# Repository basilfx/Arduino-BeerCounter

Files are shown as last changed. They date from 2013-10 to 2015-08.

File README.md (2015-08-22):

# BeerCounter
A beer cork counting system, built around an Arduino, with the love of beer.

## Contents
* Eagle schematic and PCB
* Arduino firmware

## Eagle

### Bill of materials
| Part | Value | Device | Package |
|---|---|---|---|
| C1 | 22pF | C-EU025-024X044 | C025-024X044 |
| C2 | 22pF | C-EU025-024X044 | C025-024X044 |
| C3 | 100nF | C-EU025-024X044 | C025-024X044 |
| C4 | | CPOL-EUTT2D5 | TT2D5 |
| C5 | 100nF | C-EU025-024X044 | C025-024X044 |
| IC1 | TL072P | TL072P | DIL08 |
| IC2 | MEGA8-P | MEGA8-P | DIL28-3 |
| ISP | AVR_SPI_PROG  | AVR_SPI_PROG | AVR_ICSP |
| J1 | POWER_JACKSLT | POWER_JACKSLT | POWER_JACK_SLOT |
| LDR1 | | M02LOCK | 1X02_LOCK |
| LDR2 | | M02LOCK | 1X02_LOCK |
| Q1 | 16MHz | XTAL/S | QS |
| R1 | 4k7 | R-EU_0204/7 | 0204/7 |
| R2 | 1M | R-EU_0204/7 | 0204/7 |
| R3 | 1M | R-EU_0204/7 | 0204/7 |
| R4 | 4k7 | TRIM_EU-LI10 | LI10 |
| R5 | 4k7 | TRIM_EU-LI10 | LI10 |
| R6 | 68k | R-EU_0204/7 | 0204/7 |
| R7 | 68k | R-EU_0204/7 | 0204/7 |
| R8 | 220 | R-EU_0204/7 | 0204/7 |
| R9 | 220 | R-EU_0204/7 | 0204/7 |
| R10 | 4k7 | R-EU_0204/7 | 0204/7 |
| S1 | | TAC_SWITCHPTH | TACTILE-PTH |
| S2 | | TAC_SWITCHPTH | TACTILE-PTH |

### Board render
Render of the controller board. It measures 2.05x2.30 inch

board_controller

Render of the display board. It measures 3.70x1.60 inch.

board_display

## Arduino
The source can be found under `firmware`. It's build with Arduino 1.6.5, but newer versions should work too.

You need the following libraries:
* [CommandLine](https://github.com/basilfx/Arduino-CommandLine)
* [Timer1](http://playground.arduino.cc/Code/Timer1)

### Firmware
To be done.

### Hardware configuration
For best performance, the light gate should be fitted in a tube, where environment light has little effect.

To calibrate the device, check the [calibration](https://github.com/basilfx/Arduino-BeerCounter/blob/master/docs/Calibration.md) guide.

### Firmware configuration
Once you have the device ready, connect it to the computer via a serial adapter. Hold the setup button, and power cycle the device. The settings for terminal are 115200 baud, 8 bits, no parity and 1 start/stop bit. The terminal has the following commands:

* reset &mdash; Reset the device
* count <value> &mdash; Get/set the initial count
* zeroes <1|0> &mdash; Enable/disable leading zeroes
* restarts &mdash; Get the number of power cycles

## License
See the `LICENSE` file (MIT license).

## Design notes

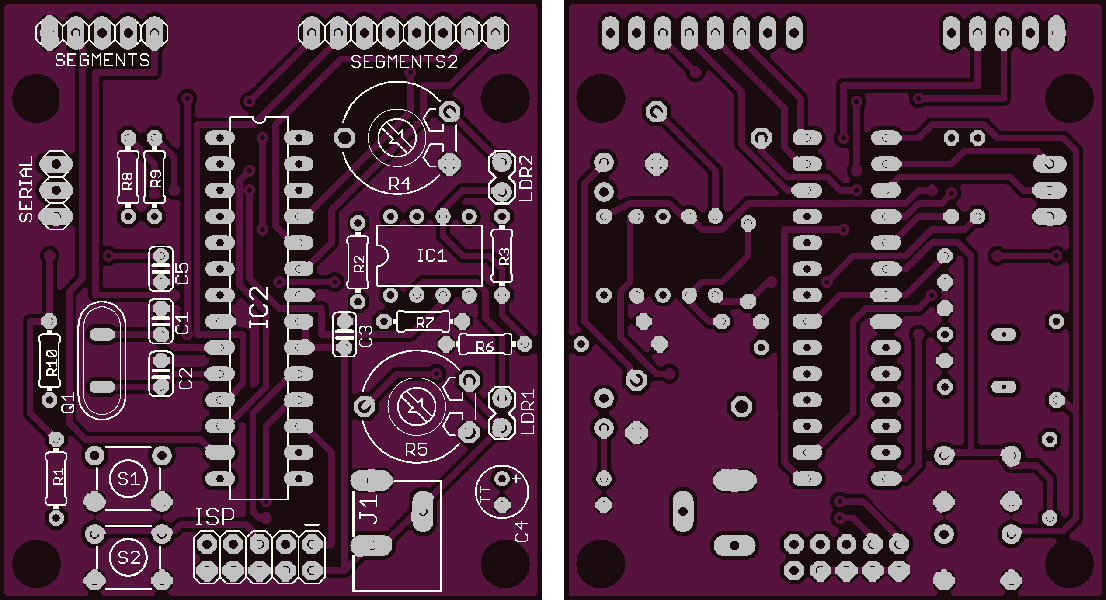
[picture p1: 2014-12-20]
docs/board_controller.png

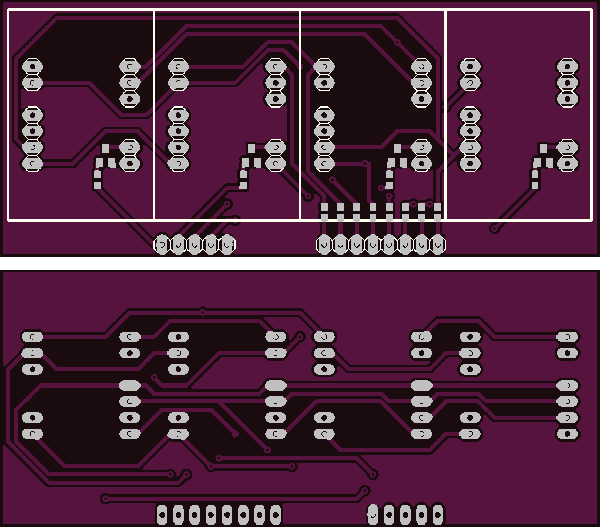
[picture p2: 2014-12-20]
docs/board_display.png

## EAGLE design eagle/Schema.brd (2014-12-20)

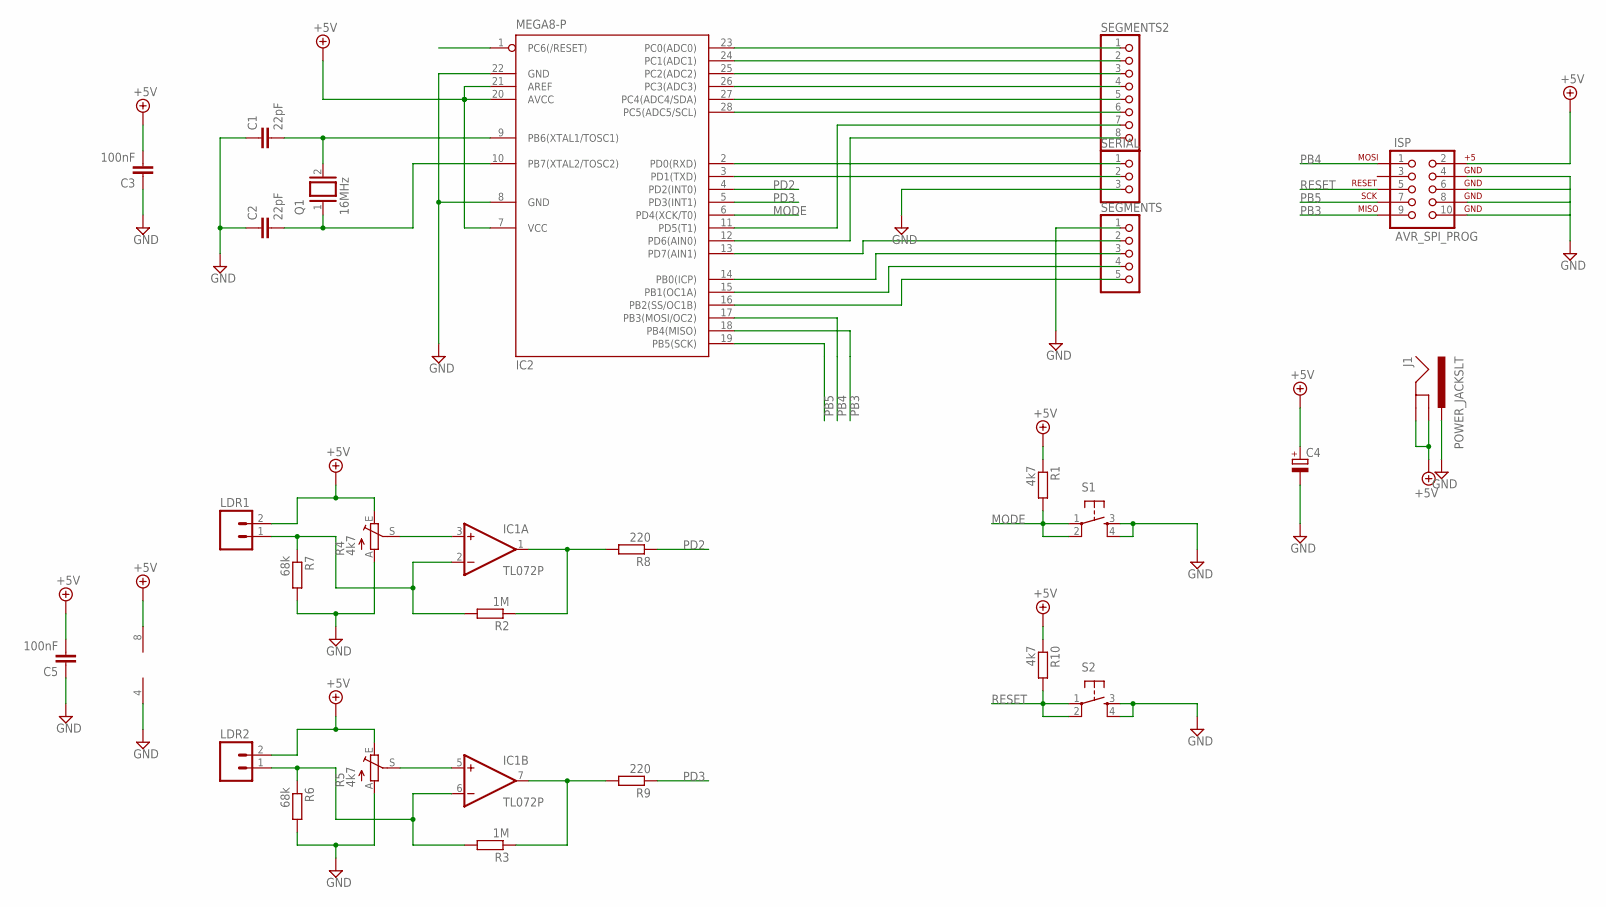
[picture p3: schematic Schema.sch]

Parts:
C1, C2: 22pF; C025-024X044
C3, C5: 100nF; C025-024X044
C4: CPOL-EUTT2D5; TT2D5
IC1: TL072P; DIL08
IC2: MEGA8-P; DIL28-3
ISP: AVR_SPI_PROG; AVR_ICSP
J1: POWER_JACKSLT; POWER_JACK_SLOT
LDR1, LDR2: M02LOCK; 1X02_LOCK
Q1: 16MHz; QS
R1, R10: 4k7; 0204/7
R2, R3: 1M; 0204/7
R4, R5: 4k7; LI10
R6, R7: 68k; 0204/7
R8, R9: 220; 0204/7
S1, S2: TAC_SWITCHPTH; TACTILE-PTH
SEGMENTS: PINHD-1X5; 1X05
SEGMENTS2: PINHD-1X8; 1X08
SERIAL: PINHD-1X3; 1X03

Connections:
+5V: C3.2, C4.+, C5.2, IC1.8 (V+), IC2.7 (VCC), IC2.20 (AVCC), IC2.21 (AREF), ISP.2, J1.GND@1 (GNDBREAK), J1.GND@2 (GND), LDR1.2, LDR2.2, R1.1, R4.E, R5.E, R10.1
GND: C1.1, C2.1, C3.1, C4.-, C5.1, IC1.4 (V-), IC2.8 (GND), IC2.22 (GND), ISP.4, ISP.6, ISP.8, ISP.10, J1.PWR, R4.A, R5.A, R6.2, R7.2, S1.3, S1.4, S2.3, S2.4, SEGMENTS.1, SERIAL.3
MODE: IC2.6 (PD4(XCK/T0)), R1.2, S1.1, S1.2
unnamed: C1.2, IC2.9 (PB6(XTAL1/TOSC1)), Q1.2
unnamed: C2.2, IC2.10 (PB7(XTAL2/TOSC2)), Q1.1
unnamed: IC1.1 (OUT), R2.1, R8.2
unnamed: IC2.3 (PD1(TXD)), SERIAL.2
unnamed: IC2.2 (PD0(RXD)), SERIAL.1
unnamed: IC1.7 (OUT), R3.1, R9.2
unnamed: IC1.3 (+IN), R4.S
unnamed: IC1.5 (+IN), R5.S
unnamed: IC1.6 (-IN), LDR2.1, R3.2, R6.1
unnamed: IC1.2 (-IN), LDR1.1, R2.2, R7.1
unnamed: IC2.16 (PB2(SS/OC1B)), SEGMENTS.5
unnamed: IC2.15 (PB1(OC1A)), SEGMENTS.4
unnamed: IC2.14 (PB0(ICP)), SEGMENTS.3
unnamed: IC2.24 (PC1(ADC1)), SEGMENTS2.2
unnamed: IC2.25 (PC2(ADC2)), SEGMENTS2.3
unnamed: IC2.26 (PC3(ADC3)), SEGMENTS2.4
unnamed: IC2.27 (PC4(ADC4/SDA)), SEGMENTS2.5
unnamed: IC2.28 (PC5(ADC5/SCL)), SEGMENTS2.6
unnamed: IC2.12 (PD6(AIN0)), SEGMENTS2.8
unnamed: IC2.11 (PD5(T1)), SEGMENTS2.7
unnamed: IC2.13 (PD7(AIN1)), SEGMENTS.2
PB3: IC2.18 (PB4(MISO)), ISP.9
PB4: IC2.17 (PB3(MOSI/OC2)), ISP.1
PB5: IC2.19 (PB5(SCK)), ISP.7
PD2: IC2.4 (PD2(INT0)), R8.1
PD3: IC2.5 (PD3(INT1)), R9.1
RESET: IC2.1 (PC6(/RESET)), ISP.5, R10.2, S2.1, S2.2
SEGMENTS: IC2.23 (PC0(ADC0)), SEGMENTS2.1

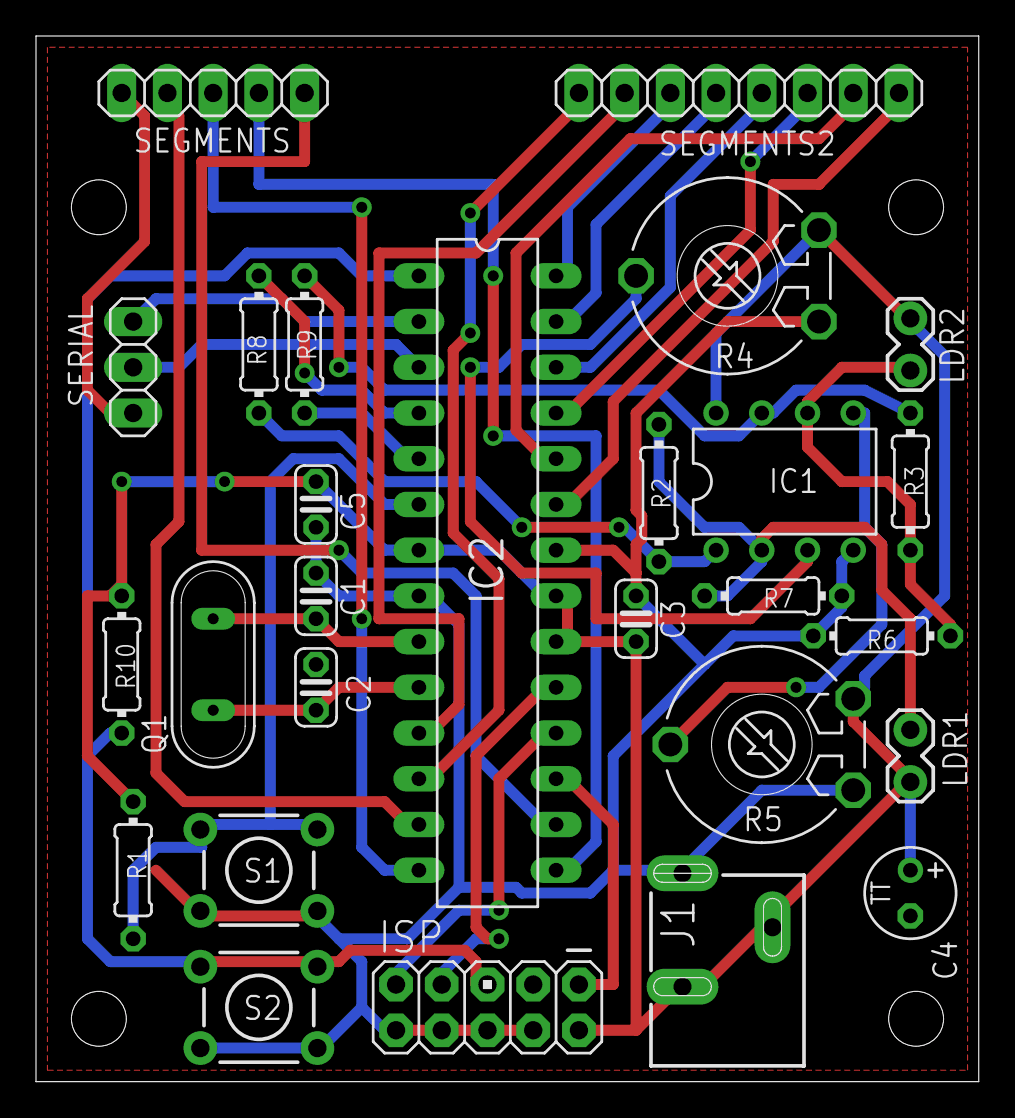
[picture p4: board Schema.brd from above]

Board: 2 copper layers, 52.4 x 58.1 mm, 31 parts (0 on the bottom side), 31 nets.

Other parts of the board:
U$2, U$3, U$4, U$5: STAND-OFF-TIGHT

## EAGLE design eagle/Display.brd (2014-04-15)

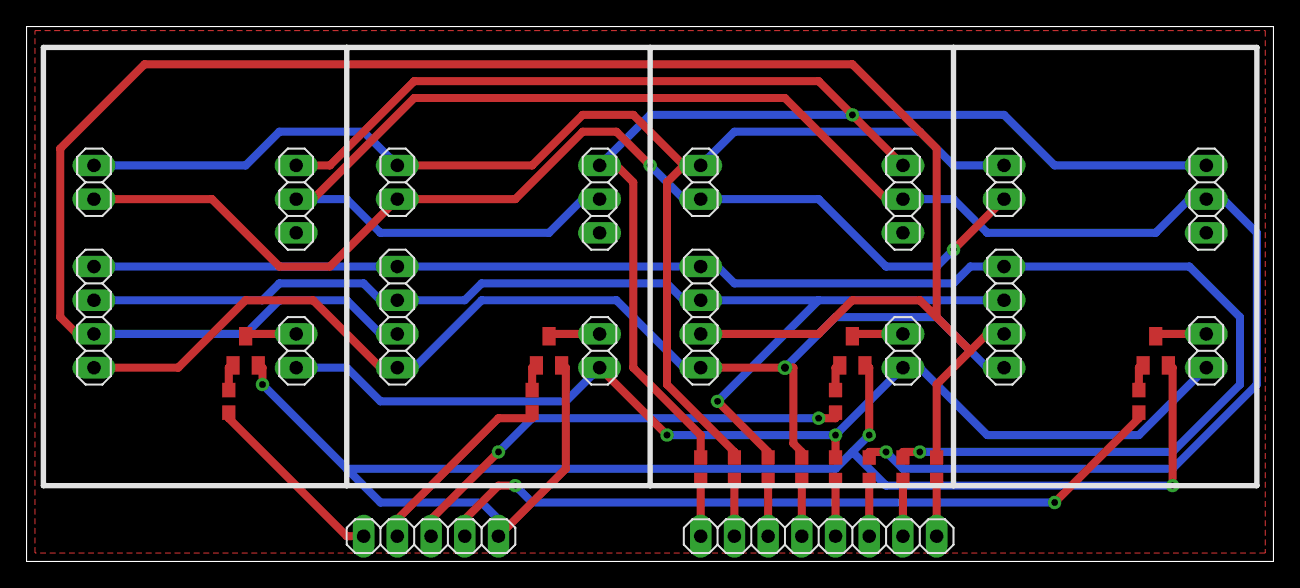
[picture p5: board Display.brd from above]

Board: 2 copper layers, 94.0 x 40.3 mm, 34 parts (0 on the bottom side), 30 nets.

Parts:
E$1, E$3, E$5, E$7, E$9, E$11, E$13, E$15: 1X02
E$2, E$6, E$10, E$14: 1X03
E$4, E$8, E$12, E$16: 1X04
E$17: 1X08
E$18, E$19, E$20, E$21, E$22, E$23, E$24, E$25, E$26, E$32, E$33, E$34: 0603
E$27, E$28, E$29, E$30: SOT23
E$31: 1X05

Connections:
GND: E$27.2, E$28.2, E$29.2, E$30.2, E$31.5
S$1: E$2.3, E$6.3, E$10.3, E$14.3, E$19.2
S$2: E$3.2, E$7.2, E$11.2, E$15.2, E$20.2
S$3: E$3.1, E$7.1, E$11.1, E$15.1
S$4: E$2.2, E$6.2, E$10.2, E$14.2, E$24.2
S$5: E$4.4, E$8.4, E$12.4, E$16.4, E$25.2
S$6: E$4.3, E$8.3, E$12.3, E$16.3, E$21.2
S$7: E$1.1, E$5.1, E$9.1, E$13.1, E$23.2
S$8: E$4.1, E$8.1, E$12.1, E$16.1, E$22.2
S$9: E$4.2, E$8.2, E$12.2, E$16.2, E$26.2
S$10: E$17.1, E$19.1
S$11: E$17.2, E$20.1
S$12: E$17.3, E$21.1
S$13: E$17.4, E$22.1
S$14: E$17.5, E$23.1
S$15: E$17.6, E$24.1
S$16: E$17.7, E$25.1
S$17: E$17.8, E$26.1
S$18: E$1.2, E$27.3
S$19: E$5.2, E$28.3
S$20: E$9.2, E$29.3
S$21: E$13.2, E$30.3
S$22: E$18.1, E$31.1
S$23: E$18.2, E$27.1
S$24: E$31.2, E$32.2
S$25: E$28.1, E$32.1
S$26: E$29.1, E$33.1
S$27: E$30.1, E$34.2
S$28: E$31.3, E$33.2
S$29: E$31.4, E$34.1

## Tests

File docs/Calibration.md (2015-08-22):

# Calibration

## Introduction
Configuring the hardware is something that has to be done with extra care. Since the detection is built around a light gate and a comparator, the potentiometers have to be tuned to the right sensitivity. The right sensitivity can be estimated by measuring the voltage across the LDR, and then tune the wiper position so the voltage across the potentiometer is a bit higher.

If you have a oscilloscope, you can hook it up to the comparator output, and measure the time of flight if you throw one cork through the sensor tube. If the time of flight is too short, or not detected, try to decrease sensitivity. Otherwise, increase it. The output of a channel should be in the range of 15-30 ms when a cork is registered. The examples below show a calibrated output.

## Examples

### One channel
This is an example for just one channel, when a cork is registered.

scope_channel

* Yellow: LDR output
* Blue: voltage reference (output of trimpot)
* Purple: channel output (feeds into Arduino)

### Both channels
This is an example reading of both channels, when a cork is registered.

scope_both

* Yellow: channel one (feeds into Arduino)
* Blue: channel two (feeds into Arduino)

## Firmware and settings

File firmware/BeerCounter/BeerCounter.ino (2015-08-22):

#include <avr/eeprom.h>
#include <TimerOne.h>
#include <CommandLine.h>
#include "Config.h"

//#define DEBUG

/**
 * CommandLine instance.
 */
CommandLine commandLine(Serial, "> ");

/**
 * Configuration structure.
 */
configuration_t configuration;

timer_t timerSave;
timer_t timerDisplay;
timer_t timerMinute;
timer_t timerBlink;
timer_t timerValidate;
timer_t timerBackoff;
timer_t* timers[] = { &timerSave, &timerDisplay, &timerMinute, &timerBlink, &timerValidate, &timerBackoff};

/**
 * Mask for the seven segment displays
 */
const byte numbers[17] = {
  0b11111100,
  0b01100000,
  0b11011010,
  0b11110010,
  0b01100110,
  0b10110110,
  0b10111110,
  0b11100000,
  0b11111110,
  0b11100110,
  0b11101110,
  0b00111110,
  0b10011100,
  0b01111010,
  0b10011110,
  0b10001110,
  0b00000000
};

uint16_t perMinute[60];
uint8_t currentMinute;
uint16_t totalPerHour;

int missedInterrupts;
byte error;
byte displays;
byte currentDisplay;

void setup() {
  // Setup pins
  setupPins();

  // Load settings
  loadSettings();
  
  // Determine program mode
  if (digitalRead(PIN_MODE) == LOW) {
    configMode(); 
  } else {
    #ifdef DEBUG
    Serial.begin(38400);
    Serial.println("Run mode");
    #endif
    
    // Increase restart count
    configuration.restarts++;
    saveSettings();
    
    // Setup normal program
    setupNormalMode();
  }
}

/**
 * Setup commandline
 */
void configMode() {
  // Setup serial
  Serial.begin(38400);
  Serial.println("Config mode");

  // Add commands
  commandLine.add("help", commandHelp);
  commandLine.add("count", commandCount); 
  commandLine.add("zeroes", commandZeroes); 
  commandLine.add("restarts", commandRestarts);
  commandLine.add("ram", commandRam);   
  commandLine.add("reset", commandReset);

  // Loop config mode until reset.
  for (;;) commandLine.update();
}

void configTimers() {
  timerSave.enabled = false;
  timerSave.count = 0;
  timerSave.value = 60000;
  timerSave.callback = &timerSaveCallback;
  
  timerDisplay.enabled = true;
  timerDisplay.count = 0;
  timerDisplay.value = 2000;
  timerDisplay.callback = &timerDisplayCallback;
  
  timerMinute.enabled = true;
  timerMinute.count = 0;
  timerMinute.value = 60000;
  timerMinute.callback = &timerMinuteCallback;

  timerBlink.enabled = true;
  timerBlink.count = 0;
  timerBlink.data = 0;
  timerBlink.value = 500;
  timerBlink.callback = &timerBlinkCallback;
  
  timerValidate.enabled = false;
  timerBlink.data = 0;
  timerValidate.count = 0;
  timerValidate.value = 5;
  timerValidate.callback = &timerValidateCallback;
  
  timerBackoff.enabled = false;
  timerBackoff.count = 0;
  timerBackoff.value = 35;
  timerBackoff.callback = &timerBackoffCallback;
}

/**
 * Setup the pins
 */
void setupPins() {
  pinMode(PIN_MODE, INPUT);
 
  pinMode(PIN_LDR1, INPUT);
  pinMode(PIN_LDR2, INPUT);

  pinMode(PIN_SEG1, OUTPUT);     
  pinMode(PIN_SEG2, OUTPUT);     
  pinMode(PIN_SEG3, OUTPUT);     
  pinMode(PIN_SEG4, OUTPUT);       

  pinMode(PIN_SEGA, OUTPUT);     
  pinMode(PIN_SEGB, OUTPUT);     
  pinMode(PIN_SEGC, OUTPUT);     
  pinMode(PIN_SEGD, OUTPUT); 
  pinMode(PIN_SEGE, OUTPUT);     
  pinMode(PIN_SEGF, OUTPUT);     
  pinMode(PIN_SEGG, OUTPUT);     
  pinMode(PIN_SEGDOT, OUTPUT);
}

void setupNormalMode() {
  // Stabilize
  delay(1000);
  
  // Attach interrupts
  attachInterrupt(INTERRUPT1, interruptDetect, RISING);
  attachInterrupt(INTERRUPT2, interruptDetect, RISING);
  
  // Set default state
  displays = DISPLAY_NORMAL;
  currentDisplay = DISPLAY_NORMAL;
  error = ERROR_NONE;
  missedInterrupts = 0;
  
  // Setup program timers
  configTimers();
  
  // Setup timer interrupt
  Timer1.initialize(1000);
  Timer1.attachInterrupt(interruptTimer);
}

/**
 * Main-loop van het programma. Handel alle tijdsintensiefe taken
 * af, afhankelijk van de variabelen
 */
void loop() {
  boolean skipDigit = true;
  boolean raw = false;
  boolean dot[4] = {false, false, false, false};
  byte digit[4];
  long power = 1000;
  long value = 0;
  
  // Determine what to display
  switch (currentDisplay) {
    case DISPLAY_NORMAL:
      value = configuration.count;
      
      dot[0] = configuration.count >= 40000;
      dot[1] = configuration.count >= 30000;
      dot[2] = configuration.count >= 20000;
      dot[3] = configuration.count >= 10000;
      
      break;
    case DISPLAY_PER_HOUR:
      value = totalPerHour;
  
      dot[0] = false;
      dot[1] = false;
      dot[2] = false;
      dot[3] = timerBlink.data;
      
      break;
    case DISPLAY_ERROR:
      raw = true;

      dot[0] = false;
      dot[1] = false;
      dot[2] = false;
      dot[3] = false;
      
      digit[3] = error;
      digit[2] = 0;
      digit[1] = 0;
      digit[0] = 0x0E;
      break;
  }
    
  // Convert value into value per digit if not raw
  if (!raw) {
    for (int i = 0; i < 4; i++) {
       digit[i] = (value / power) % 10;
       power = power / 10;
       
       if (!configuration.zeroes && digit[i] == 0 && skipDigit && i != 3) {
         digit[i] = 16; // numbers[16] = 0b00000000
       } else {
         skipDigit = false;
       }
    }
  }

  // Display the digits
  updateSegment(4, digit[0], dot[0]);
  updateSegment(3, digit[1], dot[1]);
  updateSegment(2, digit[2], dot[2]);
  updateSegment(1, digit[3], dot[3]);
}

void updateSegment(byte segment, byte number, boolean dot) {
    digitalWrite(PIN_SEG1, LOW);
    digitalWrite(PIN_SEG2, LOW);
    digitalWrite(PIN_SEG3, LOW);
    digitalWrite(PIN_SEG4, LOW);      
  
    digitalWrite(PIN_SEGA, (numbers[number] & 0b10000000));  
    digitalWrite(PIN_SEGB, (numbers[number] & 0b01000000)); 
    digitalWrite(PIN_SEGC, (numbers[number] & 0b00100000)); 
    digitalWrite(PIN_SEGD, (numbers[number] & 0b00010000)); 
    digitalWrite(PIN_SEGE, (numbers[number] & 0b00001000)); 
    digitalWrite(PIN_SEGF, (numbers[number] & 0b00000100)); 
    digitalWrite(PIN_SEGG, (numbers[number] & 0b00000010)); 
    digitalWrite(PIN_SEGDOT, dot); 
      
    if (segment == 1)
      digitalWrite(PIN_SEG1, HIGH);
    if (segment == 2)
      digitalWrite(PIN_SEG2, HIGH);
    if (segment == 3)
      digitalWrite(PIN_SEG3, HIGH);
    if (segment == 4)
      digitalWrite(PIN_SEG4, HIGH); 
     
    delay(5);
}

/**
 * Wordt aangeroepen zodra een dopje detected wordt
 *
 * Omdat het kan zijn dat een dopje meerdere signalen afgeeft, kan er 
 * slechts een volgende interrupt plaatsvinden zodra de eerste is afgehandeld
 * door de timer (na 200-300ms)
 */
void interruptDetect() {  
  // Disable interrupts
  noInterrupts();
  
  // Enable validation timer
  if (timerValidate.data == 0) {
    timerValidate.count = 0;
    timerValidate.data = 1;
    timerValidate.enabled = true;
  }
  
  // Re-enable interrupts
  interrupts();
}

void interruptTimer() {
  for (int i = 0; i < 6; i++) {
    if (timers[i]->enabled == true) {
      timers[i]->count++;
     
      if (timers[i]->count > timers[i]->value) {
        noInterrupts();
        timers[i]->count = 0;
        timers[i]->callback();
        interrupts();
      }
    }
  }
}

void timerValidateCallback() {
  // Disable this timer
  timerValidate.enabled = false;
  
  // Increment count IF one of the pins is still high
  if (digitalRead(PIN_LDR1) == HIGH || digitalRead(PIN_LDR2) == HIGH) {
    // Increment total count
    configuration.count++;
    
    // Update per hour stats (including current)
    displays |= DISPLAY_PER_HOUR;
    perMinute[currentMinute]++;
    totalPerHour++;

    // Check for errors
    if (totalPerHour > 15) {
      error |= ERROR_TOO_MANY;
      displays |= DISPLAY_ERROR;
      
      #ifdef DEBUG
      Serial.println("Too many");
      #endif
    }
    
    // Schedule a save event
    timerSave.count = 0;
    timerSave.enabled = true;
    
    // Ensure current count is displayed
    timerDisplay.count = 0;
    currentDisplay = DISPLAY_NORMAL;
    
    #ifdef DEBUG
    Serial.println("Int ACK");
    #endif
    
    // Enable timer for backoff period
    timerBackoff.count = 0;
    timerBackoff.enabled = true;
  } else {
    missedInterrupts++;
    
    if (missedInterrupts > 5) {
      error |= ERROR_MISSED_INTERRUPTS;
      displays |= DISPLAY_ERROR;
    }
    
    // Reset validation timer
    timerValidate.data = 0;
    
    #ifdef DEBUG
    Serial.println("Int NAK");
    #endif
  }
}

void timerBackoffCallback() {
  #ifdef DEBUG
  Serial.println("Backoff");
  #endif
    
  // Disable this timer
  timerBackoff.enabled = false;
  
  // Reset validation timer
  timerValidate.data = 0;
}

void timerSaveCallback() {
  #ifdef DEBUG
  Serial.println("Save");
  #endif
  
  // Save to EEPROM
  saveSettings();
   
  // Clear timer
  timerSave.enabled = false;
}

void timerDisplayCallback() {
  static byte index = 0;
  
  // Handle current display
  switch (currentDisplay) {
    case DISPLAY_PER_HOUR:
      displays &= ~DISPLAY_PER_HOUR;
      break;
  }
  
  // Determine next display
  if (index == 0) {
    index = 8;
  }
  
  while (index--) {
    if (displays & (1 << index)) {
      break;
    }
  }
  
  // Set display
  currentDisplay = (1 << index);
}

void timerMinuteCallback() {
  #ifdef DEBUG
  Serial.println("Minute");
  #endif

  // Increment current minute
  currentMinute = (currentMinute + 1) % 60;
  perMinute[currentMinute] = 0;

  // Update the total per hour
  totalPerHour = 0;
  
  for (int i = 0; i < 60; i++) {
     totalPerHour += perMinute[i];
  }
}

void timerBlinkCallback() {
  timerBlink.data = !timerBlink.data;
}

void saveSettings() {
  // Insert validation token
  configuration.magic = 0xAA;
  
  eeprom_write_block((const void *) &configuration, (void *) 0, sizeof(configuration)); 
}

void loadSettings() {
  eeprom_read_block((void *) &configuration, (void *) 0, sizeof(configuration));
  
  // Load default values if magic token is wrong
  if (configuration.magic != 0xAA) {
    configuration.count = 0;
    configuration.zeroes = false;
    configuration.restarts = 0;
  }
}

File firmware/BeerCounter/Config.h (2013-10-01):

#ifndef CONFIG_H
#define CONFIG_H

// Pin settings
#define PIN_MODE 4
#define PIN_LDR1 2
#define PIN_LDR2 3

#define PIN_SEG1 10
#define PIN_SEG2 7
#define PIN_SEG3 8
#define PIN_SEG4 9

#define PIN_SEGDOT A0
#define PIN_SEGG A1
#define PIN_SEGF A2
#define PIN_SEGE A3
#define PIN_SEGD A4
#define PIN_SEGC A5
#define PIN_SEGB 5
#define PIN_SEGA 6 

// Interrupts
#define INTERRUPT1 0
#define INTERRUPT2 1

// Display states
#define DISPLAY_NORMAL 0x01
#define DISPLAY_PER_HOUR 0x02
#define DISPLAY_ERROR 0x04

#define ERROR_NONE 0x00
#define ERROR_TOO_MANY 0x01
#define ERROR_MISSED_INTERRUPTS 0x02

// Definitions
struct configuration_t {
  unsigned int magic;
  unsigned long count;
  unsigned long restarts;
  bool zeroes;
};

struct timer_t {
  bool enabled;
  unsigned long count;
  unsigned long value;
  unsigned long data;
  void (*callback)();
};

#endif

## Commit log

2014-04-15 Updated schematics
    [Display.brd, Display.sch, Schema.brd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]
2014-12-20 Added board render and BOM
    [Schema.brd]
2015-08-22 Updated docs with information about calibration.

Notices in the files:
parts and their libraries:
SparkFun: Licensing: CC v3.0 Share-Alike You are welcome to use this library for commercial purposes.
